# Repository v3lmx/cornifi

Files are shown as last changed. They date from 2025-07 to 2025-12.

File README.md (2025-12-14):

# cornifi keyboard

The cornifi keyboard is a split keyboard based on the [corne](https://github.com/foostan/crkbd) with the physical layout of the [fifi](https://github.com/raychengy/fifi_split_keeb).

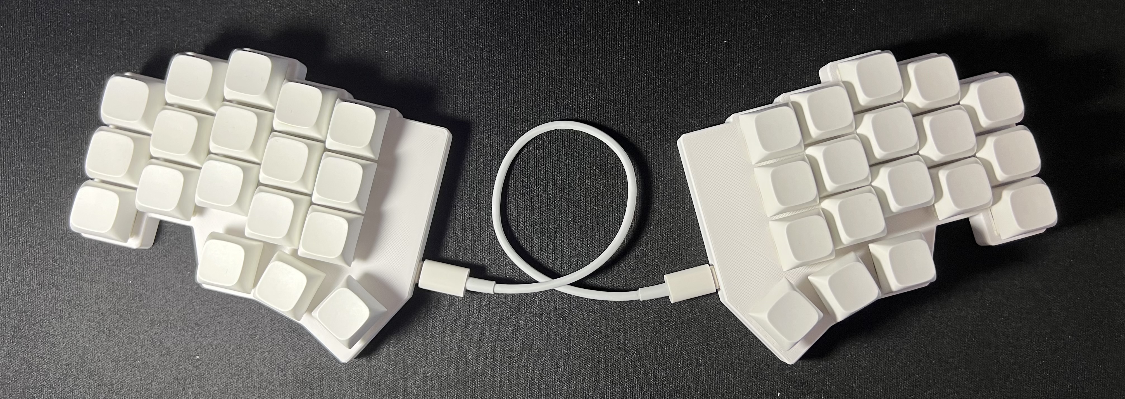
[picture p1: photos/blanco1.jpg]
cornifi keybord photo


## Features 

- 36/40 keys 
- Encoder support 
- Embedded RP2040 controller
- USB-C to connect the halves
- PCB assembly: no soldering required (unless you use encoders)

**Does not have:**
- OLED displays
- RGB
- wireless

## How to get one 

You can order a cornifi keyboard PCB from a PCB manufacturer. See the [pcb ordering guide](docs/pcb_ordering_guide.md).
Cases can be 3d printed, see the [cases](cases/) directory.
You will also need a usb-c cable, cherry MX switches, and keycaps.

I am not currently selling them myself, but if you would be interested, you can vote on [this issue](https://github.com/v3lmx/cornifi/issues/1).

## Firmware

Only [qmk](https://github.com/qmk/qmk_firmware) is supported.

The keyboard is available in the QKM master branch with documentation on installation [here](https://github.com/qmk/qmk_firmware/tree/master/keyboards/cornifi)

### Keymap

There is a default keymap available, but to make your own, I recommend using the [userspace](https://docs.qmk.fm/newbs_external_userspace) feature. You can see an example with my keymap at [v3lmx/qmk_userspace](https://github.com/v3lmx/qmk_userspace).

## Contributing

I'm open to contributions, feel free to open an issue or a pull request.

I probably won't make any changes myself, the current form has everything I need. (Also I probably don't know how).

However, if you submit a pull request, I will gladly take a look at it. Don't hesitate to discuss your ideas in an issue first. 

## Acknowledgements

- foostan for the original [corne keyboard](https://github.com/foostan/crkbd)
- raychengy for the [fifi keyboard](https://github.com/raychengy/fifi_split_keeb)
- [Supul](https://www.fiverr.com/circuitwork32) for the PCB design

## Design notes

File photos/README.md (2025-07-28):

# photos 

## 36 keys



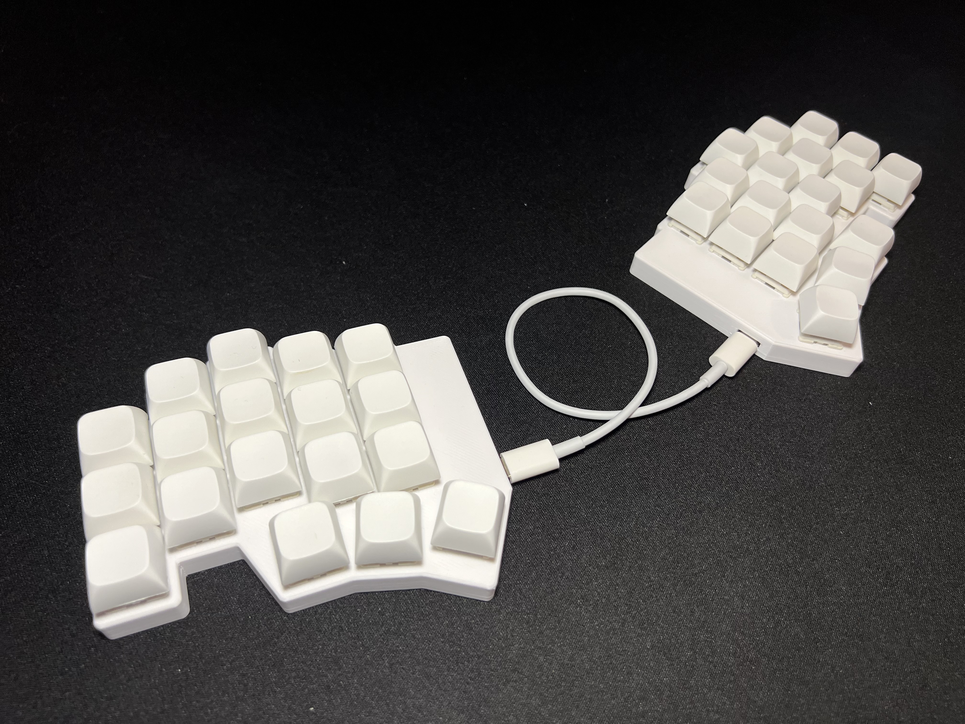
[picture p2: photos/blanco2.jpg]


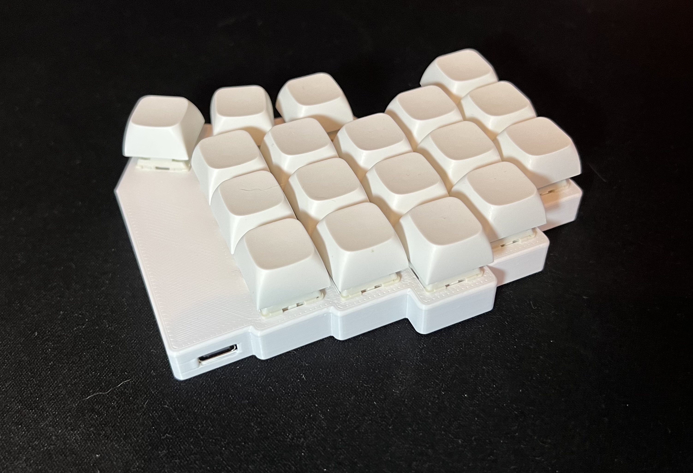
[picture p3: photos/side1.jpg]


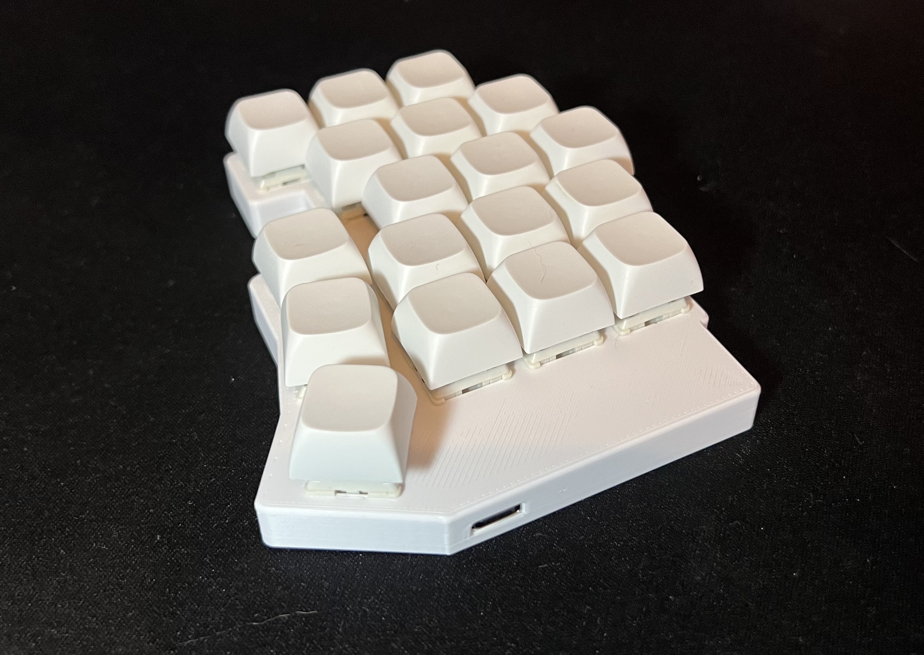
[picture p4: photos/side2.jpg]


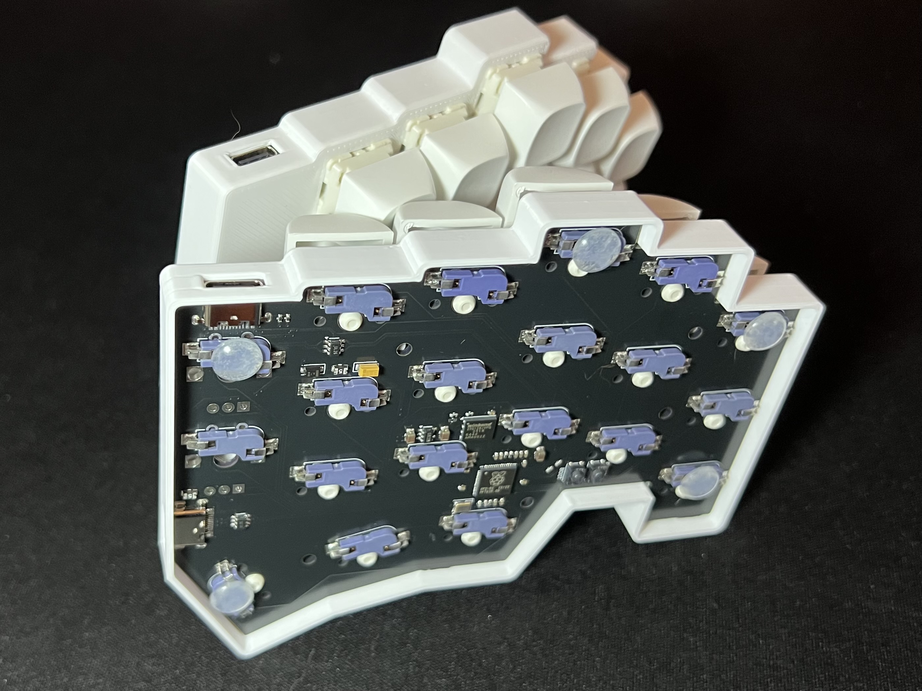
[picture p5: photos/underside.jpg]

>note: this is a preproduction pcb, the through holes are slightly smaller than the final version

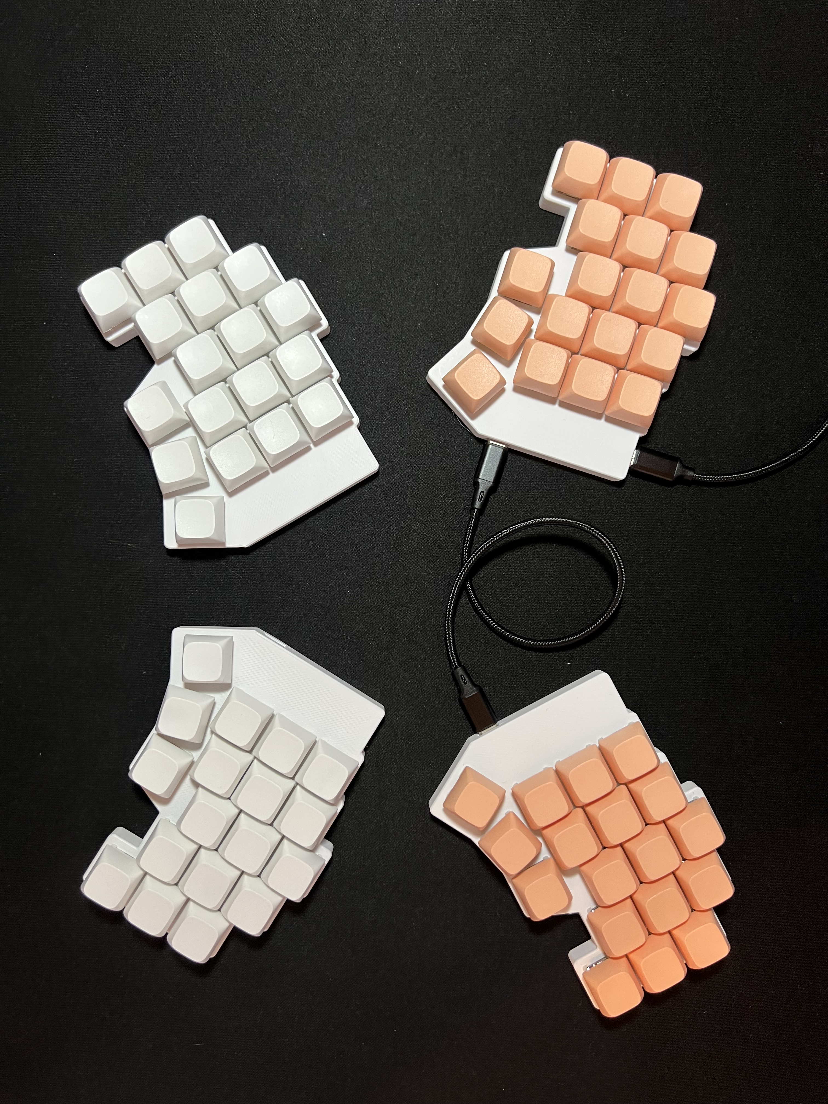
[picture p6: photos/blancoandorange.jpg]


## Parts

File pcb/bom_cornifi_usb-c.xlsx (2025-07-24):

Designator | Qnty | Comment | Footprint | LCSC Part # | MPN
C80,C81,C98,C99 | 4 | 33pF | 402 | C1562
C82,C100 | 2 | 47uF | 3216-10 | C561853
C83,C84,C97,C101,C102,C115 | 6 | 10uF | 805 | C440198
C85,C86,C103,C104 | 4 | 1uF | 402 | C52923
C89,C107,C87,C88,C90,C91,C92,C93,C94,C95,C96,C105,C106,C108,C109,C110,C111,C112,C113,C114 | 20 | 100nF | 402 | C307331
D1,D3 | 2 | PMEG3020EH | SOD-123F | C167645
F3,F4,F5,F6 | 4 | BSMD0805-050-24V | 805 | C910822
J2,J3,J4,J5 | 4 | USB_C | SMD | C2848620
R10,R11,R19,R20 | 4 | 22R | 402 | C25092
R12,R13,R21,R22 | 4 | 1k | 402 | C11702
R14,R23 | 2 | 100k | 402 | C25741
R15,R16,R17,R18,R24,R25,R26,R27 | 8 | 5.1k | 402 | C25905
SW56,SW57,SW58,SW59,SW60,SW61,SW62,SW63,SW64,SW67,SW68,SW69,SW70,SW71,SW72,SW73,SW74,SW75,SW76,SW77,SW78,SW79,SW80,SW81,SW82,SW83,SW84,SW85,SW86,SW87,SW88,SW89,SW90,SW91,SW92,SW93,SW94,SW95,SW96,SW97 | 40 | CPG151101S11 | SMD,14.5x5.9mm | C41430893
SW65,SW66 | 2 | BOOT | SMD | C116501
SW98,SW99 | 2 | RESET | SMD | C116501
U1,U3,U9,U10 | 4 | USBLC6-2SC6 | SOT-23-6 | C7519
U2,U4 | 2 | XC6210B332MR | SOT-23-5 | C424705
U5,U7 | 2 | RP2040 | Package_DFN_QFN:QFN-56-1EP_7x7mm_P0.4mm_EP3.2x3.2mm | C2040
U6,U8 | 2 | W25Q128JVPIQ | WSON-8-EP(5x6) | C190862
Y2,Y3 | 2 | 12MHz | 3225 | C9002

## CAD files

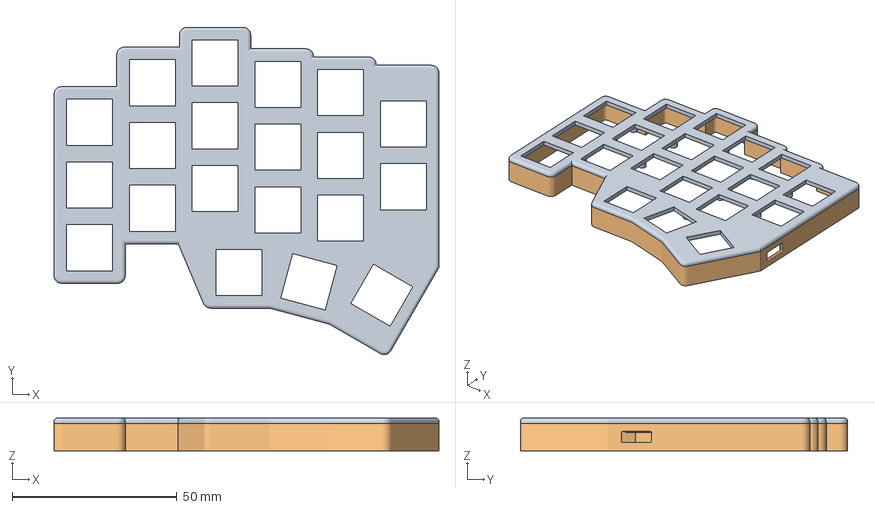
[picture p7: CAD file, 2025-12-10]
cases/cornifi-case-40-v17.3mf
116.9 x 99.4 x 10.0 mm

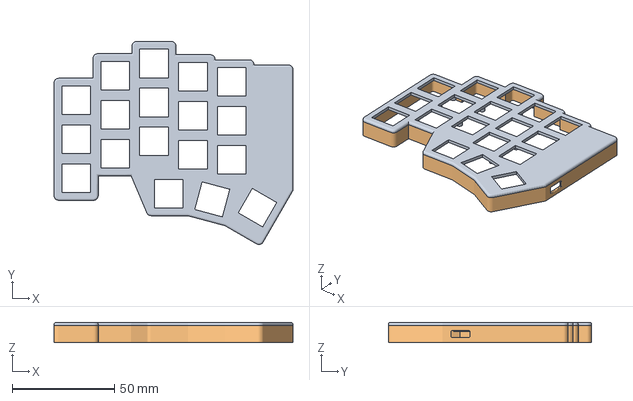
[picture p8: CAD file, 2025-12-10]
cases/cornifi-case-36-v17.3mf
116.9 x 99.4 x 10.0 mm

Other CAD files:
cases/cornifi-case-36-v17.f3d
cases/cornifi-case-40-v17.f3d

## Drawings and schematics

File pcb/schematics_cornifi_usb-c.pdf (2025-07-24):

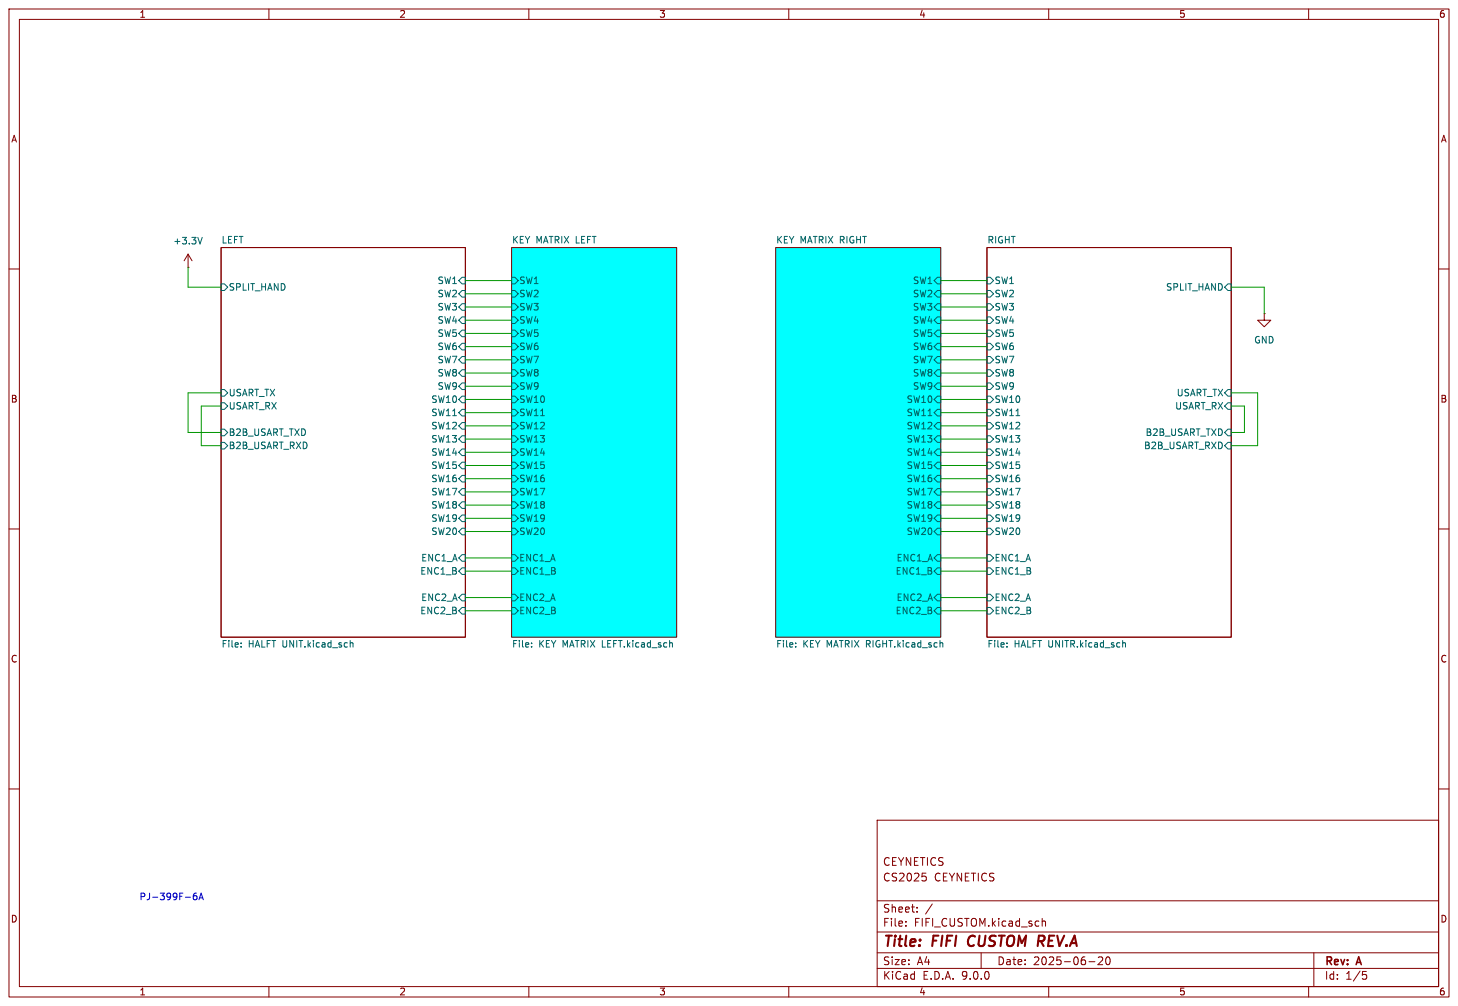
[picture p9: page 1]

File: KEY MATRIX LEFT.kicad_sch SPLIT_HAND

File: KEY MATRIX RIGHT.kicad_sch

File: FIFI_CUSTOM.kicad_sch Sheet: / CS2025 CEYNETICS CEYNETICS

Id: 1/5 Title: FIFI CUSTOM REV.A

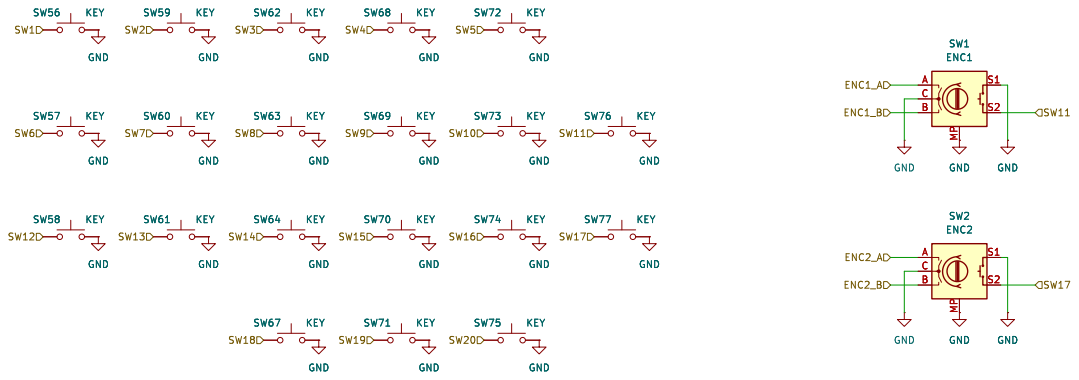
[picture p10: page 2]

Id: 2/5 Title: FIFI CUSTOM REV.A

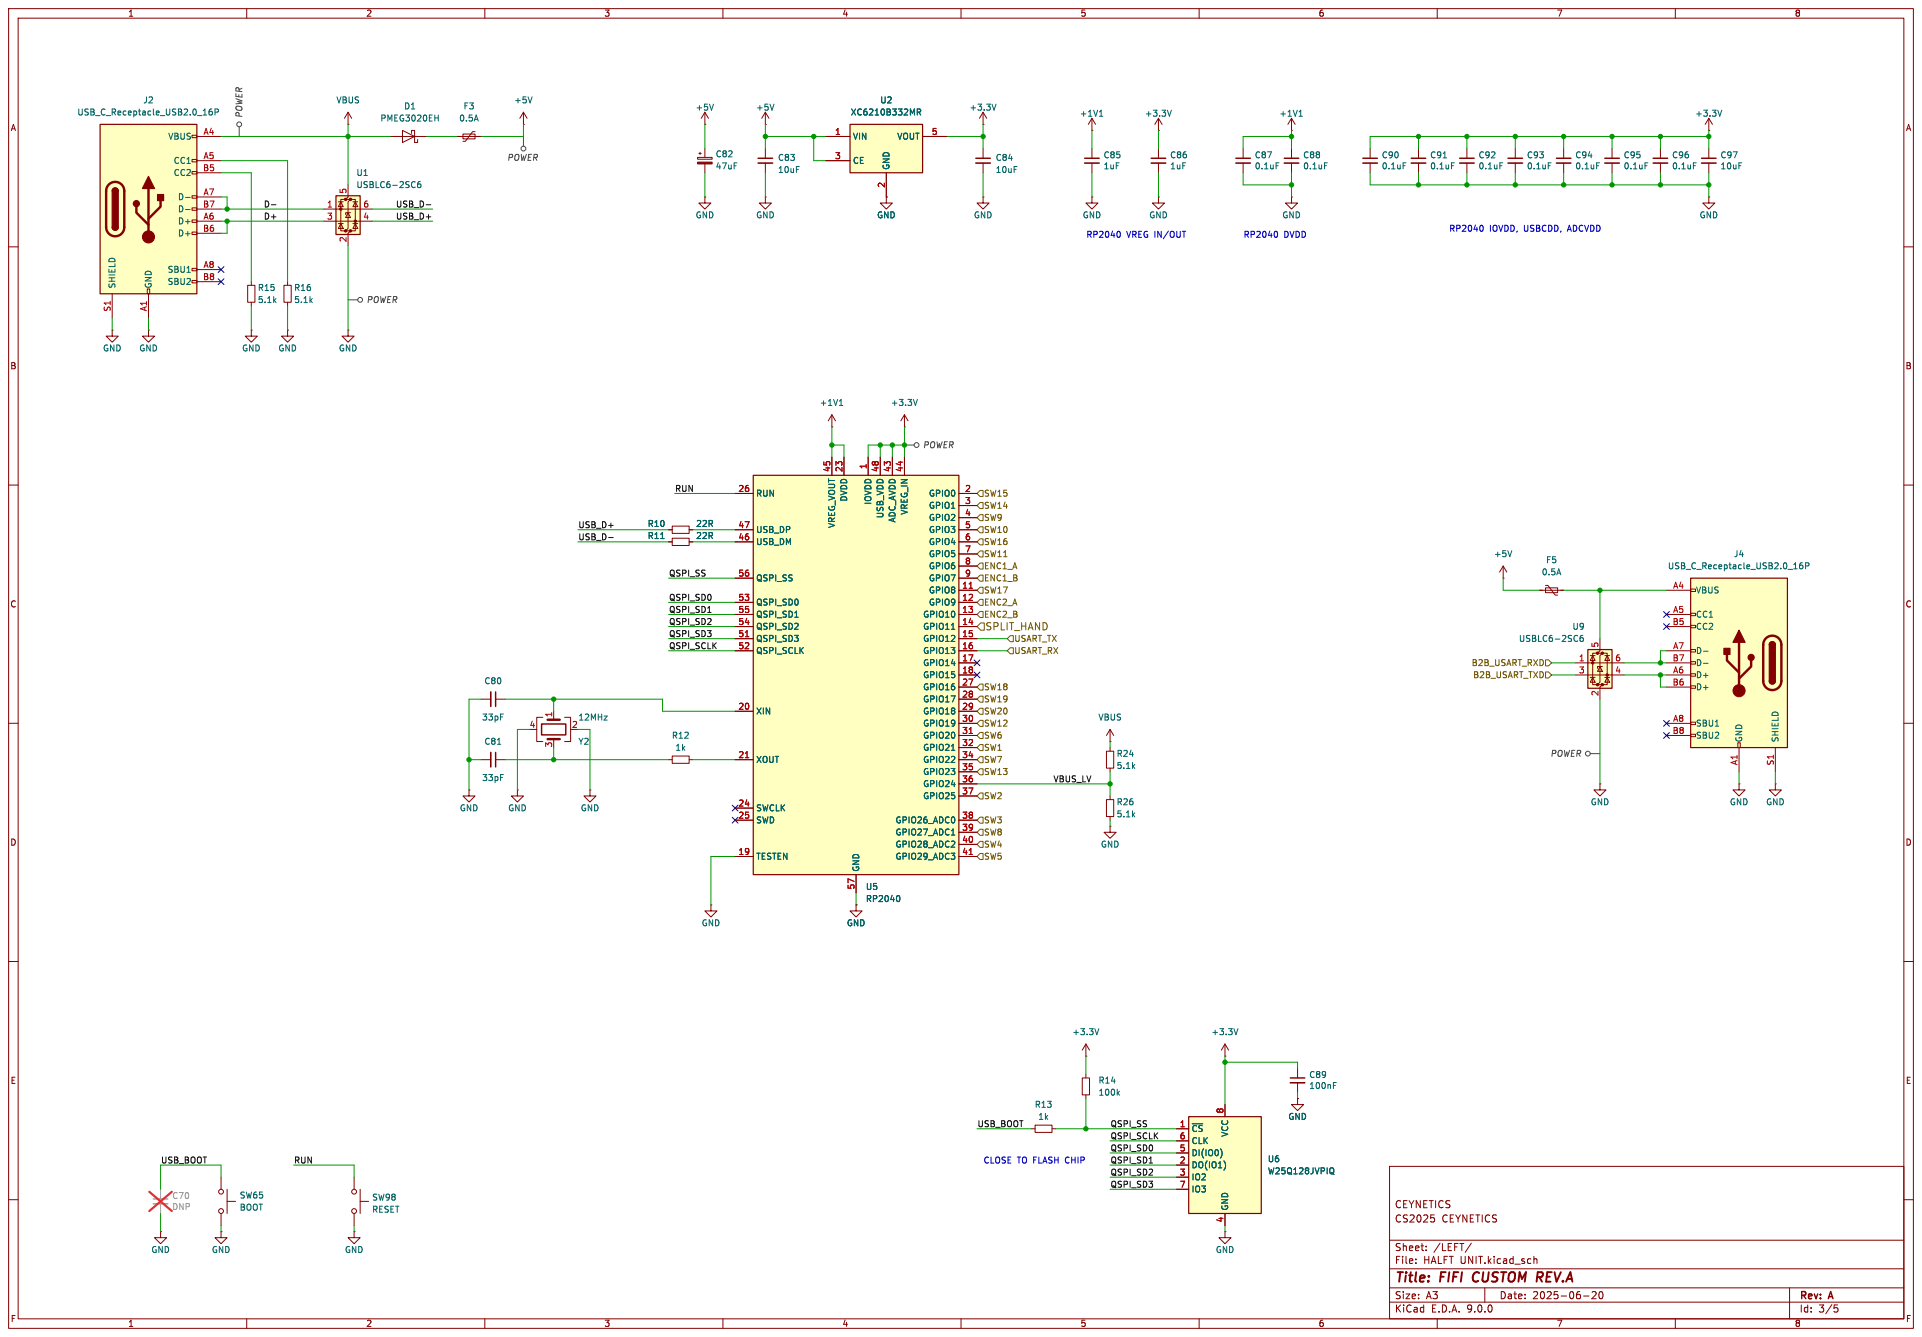
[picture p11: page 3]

~{CS} 1 CLK 6 DI(IO0) 5 DO(IO1) 2

CLOSE TO FLASH CHIP

Id: 3/5 Title: FIFI CUSTOM REV.A

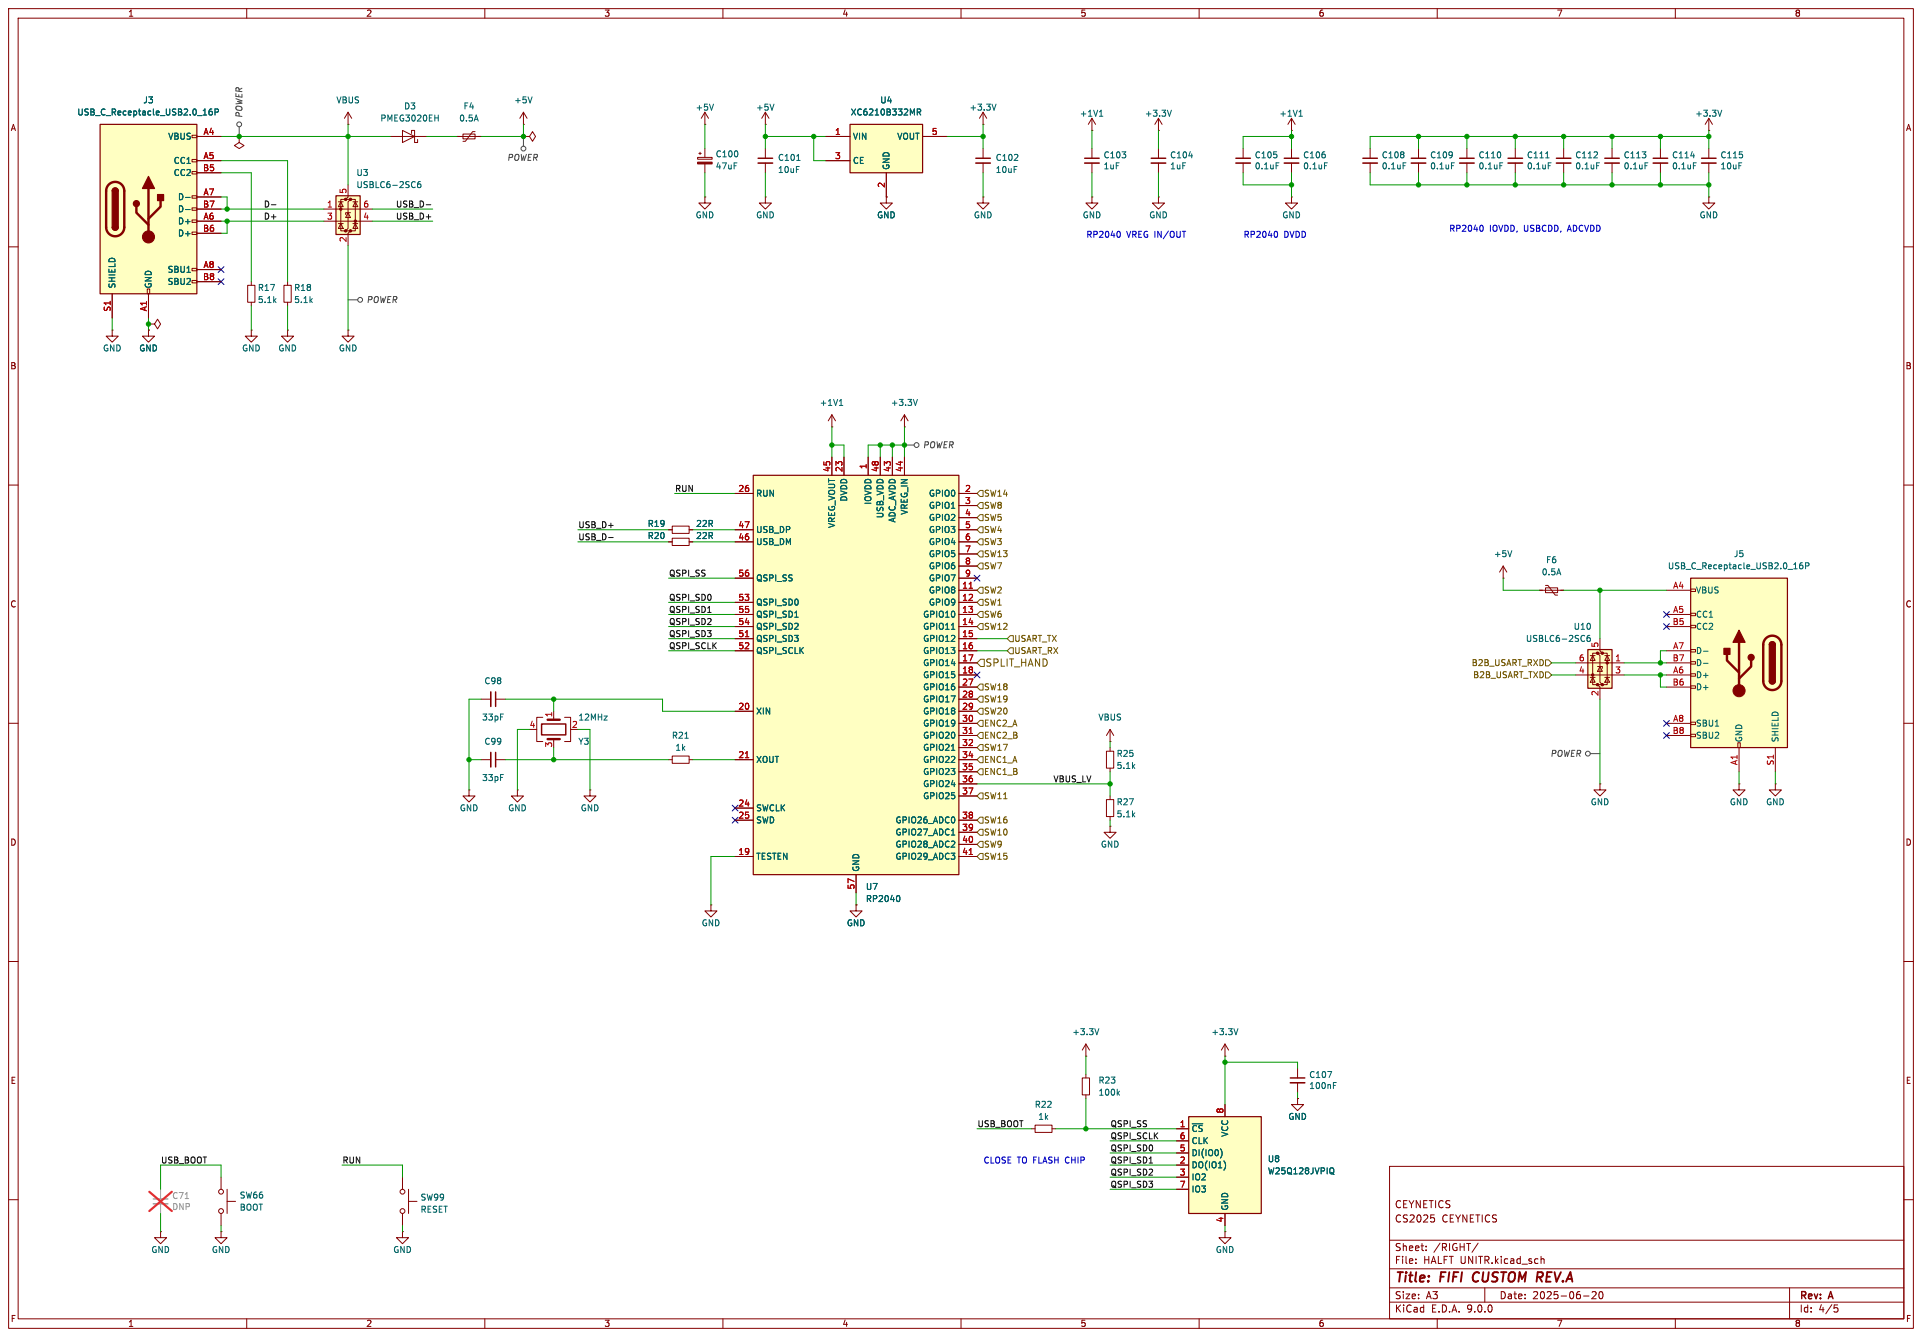
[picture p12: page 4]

CLOSE TO FLASH CHIP GND

~{CS} 1 CLK 6 DI(IO0) 5 DO(IO1) 2

Id: 4/5 Title: FIFI CUSTOM REV.A

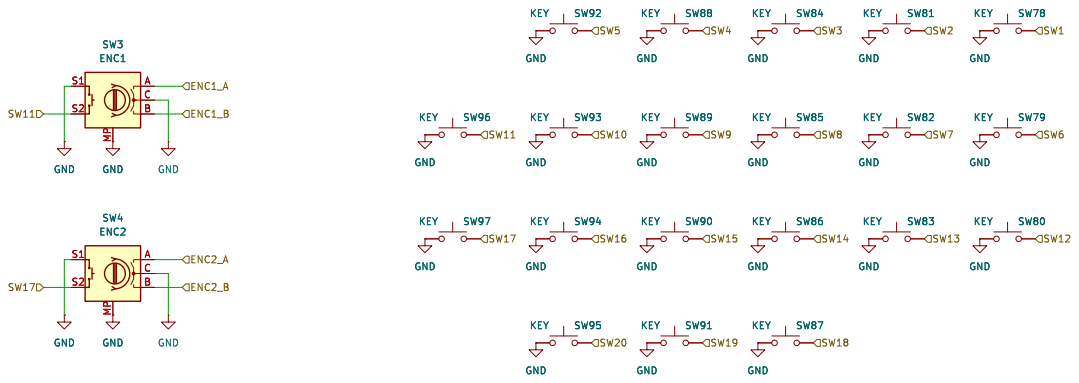
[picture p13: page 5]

Id: 5/5 Title: FIFI CUSTOM REV.A

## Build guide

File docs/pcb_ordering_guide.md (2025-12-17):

# PCB Ordering Guide

This guide will show an example of how to order the cornifi PCB on [JLPCB](https://jlcpcb.com/).

> This does not include other components needed for the keyboard: a case, switches, keycaps, and a usb-c cable.

---

1. Download the files found under `pcb/` (gerber, bom, and cpl).

1. Go to JLCPCB and select "Order Now" on the top right corner.

2. Click on "Add gerber file" and upload the gerber file: `pcb/gerber_cornifi_usb-c.zip` (this may take a while).

3. Most settings default values are good, you need to change this one :
- Different design: 2

And optionnally you can change these as well:
- PCB color: whatever you like
- Surface Finish: LeadFree HASL

> The Dimensions may change when adding PCB assembly, don't worry about it

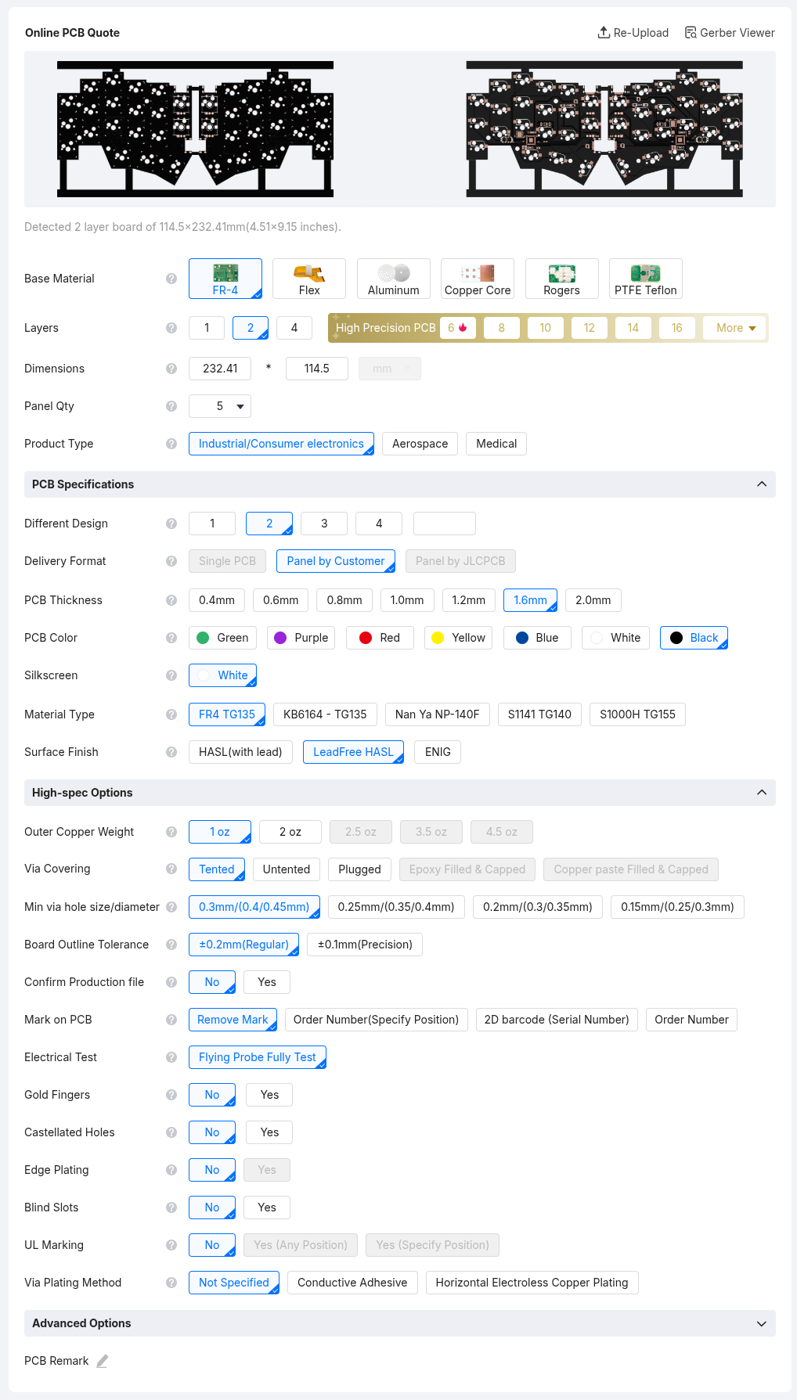
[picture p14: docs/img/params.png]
pcb settings


4. At the bottom, enable "PCB Assembly"
- PCBA Type: Standard
- Assembly Side: Bottom Side
- Confirm Parts Placement: **Yes** (this is important)

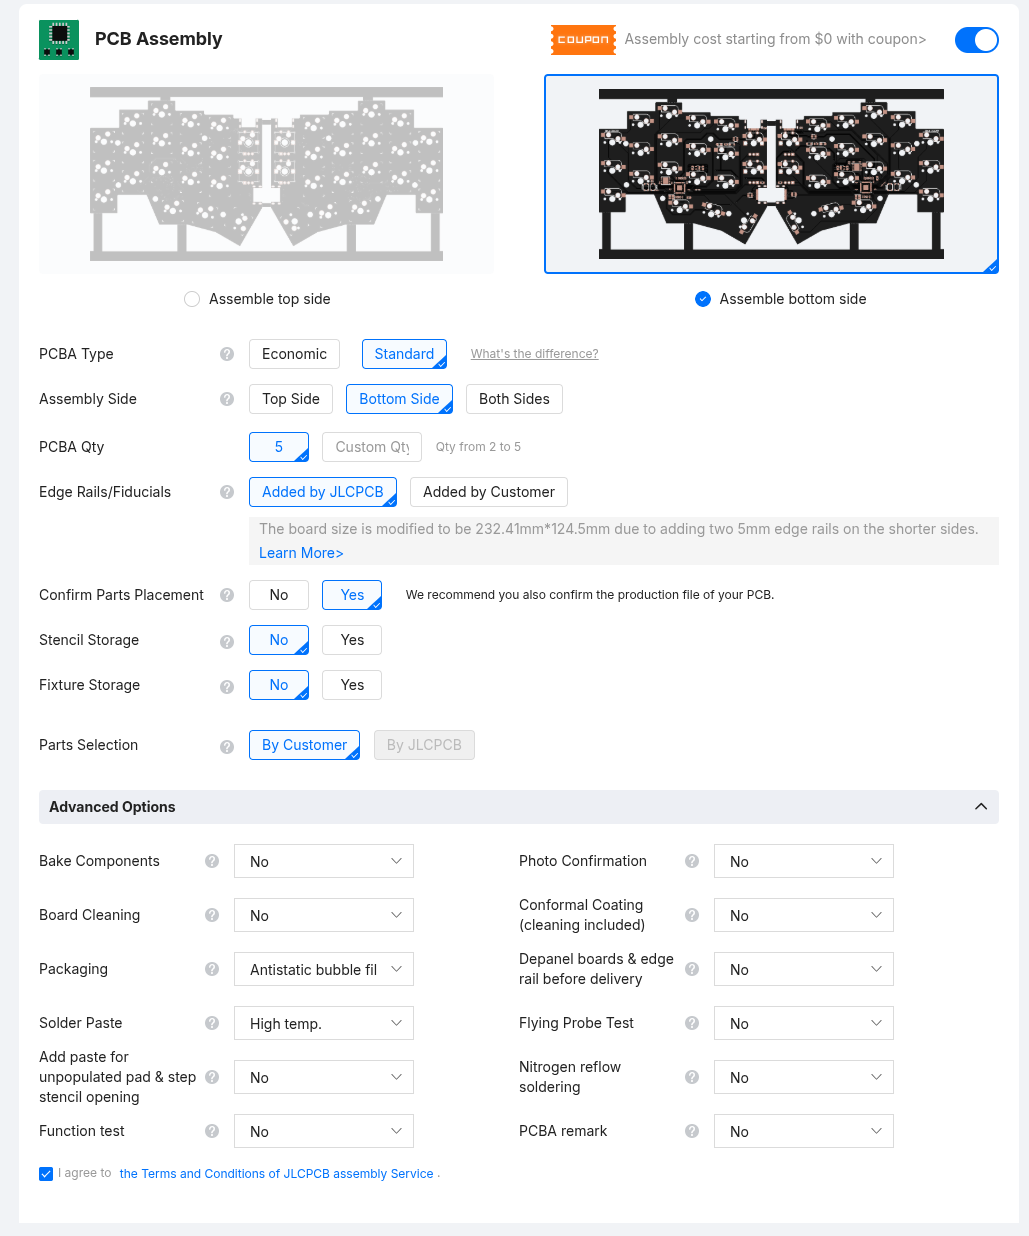
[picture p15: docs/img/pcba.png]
pcba settings


5. Click "Next", you will see you PCB, click "Next" again.

6. You should see two upload boxes, for the CPL and BOM files, and click "Next".
- BOM: `pcb/bom_cornifi_usb-c.xslx`
- CPL: `pcb/cpl_cornifi_usb-c.xslx`

7. You will see a list of components to be assembled. Some manual adjustments may be needed, check if there are any warnings or unselected components:

warning

You need to select all components before going further, so resolve all the warnings or select any missing components, then click "Next".

8. You will then see the PCB with the components placed for assembly. They will most likely be in the wrong spot, but the option "Confirm Parts Placement" will enable a JLCPCB engineer to correct the placement. [0]

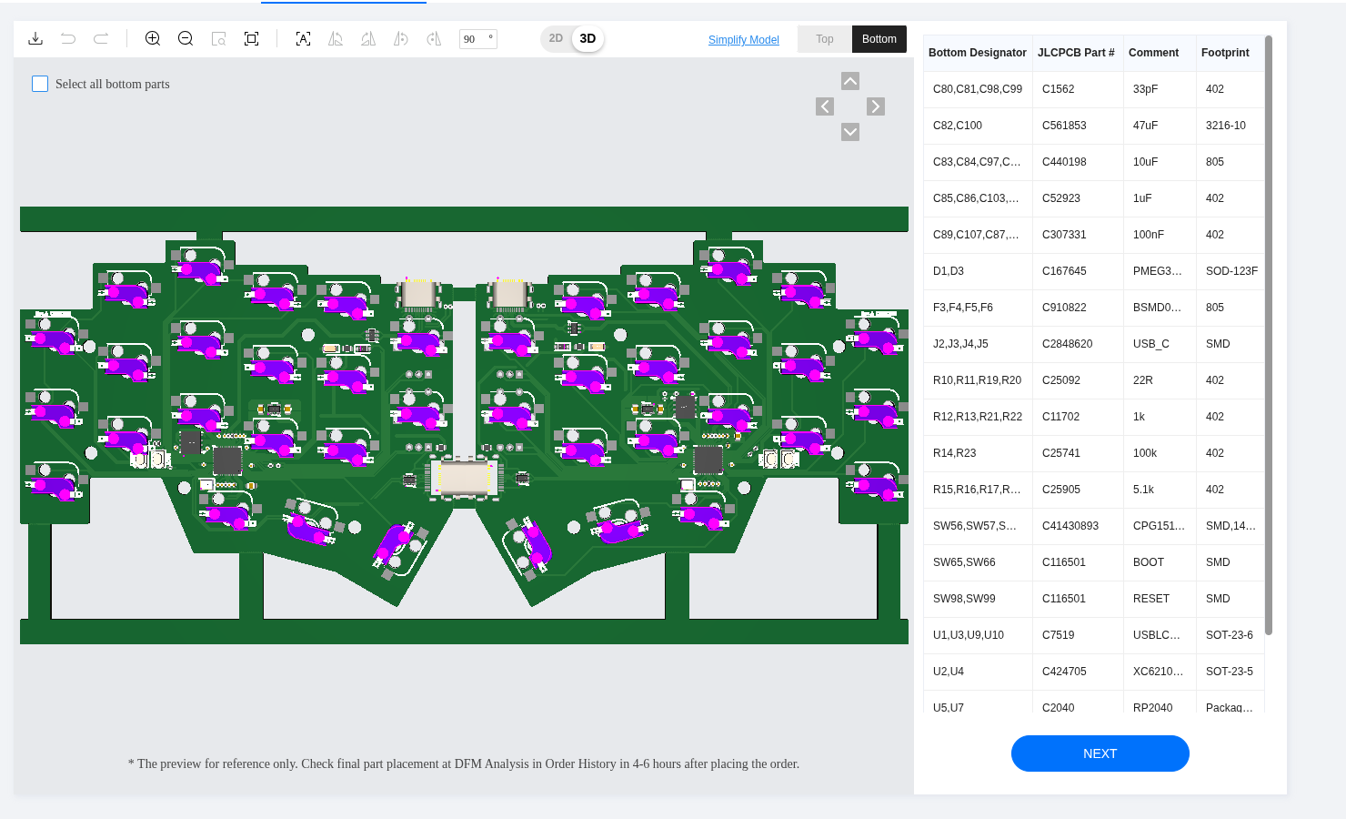
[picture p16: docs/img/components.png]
components


9. Choose the Product Category: "Office Appliance and Accessories", then "Keyboard".

10. Save to cart, and voilà!

> [0] There is a bug when uploading gerber generated with KiCad to JLCPCB that messes up the placement of components, but it will be fixed by them as long as you enable the "Confirm Parts Placement" option.

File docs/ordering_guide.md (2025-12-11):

# Ordering Guide

This guide will show an example of how to order this keyboard on [JLPCB](https://jlcpcb.com/).

---

1. Download the files found under `pcb/` (gerber, bom, and cpl).

1. Go to JLCPCB and select "Order Now" on the top right corner.

2. Click on "Add gerber file" and upload the gerber file: `pcb/gerber_cornifi_usb-c.zip` (this may take a while).

3. Most settings default values are good, here are the ones you may want to change:
    1. PCB color: whatever you like
    1. Surface Finish: LeadFree HASL

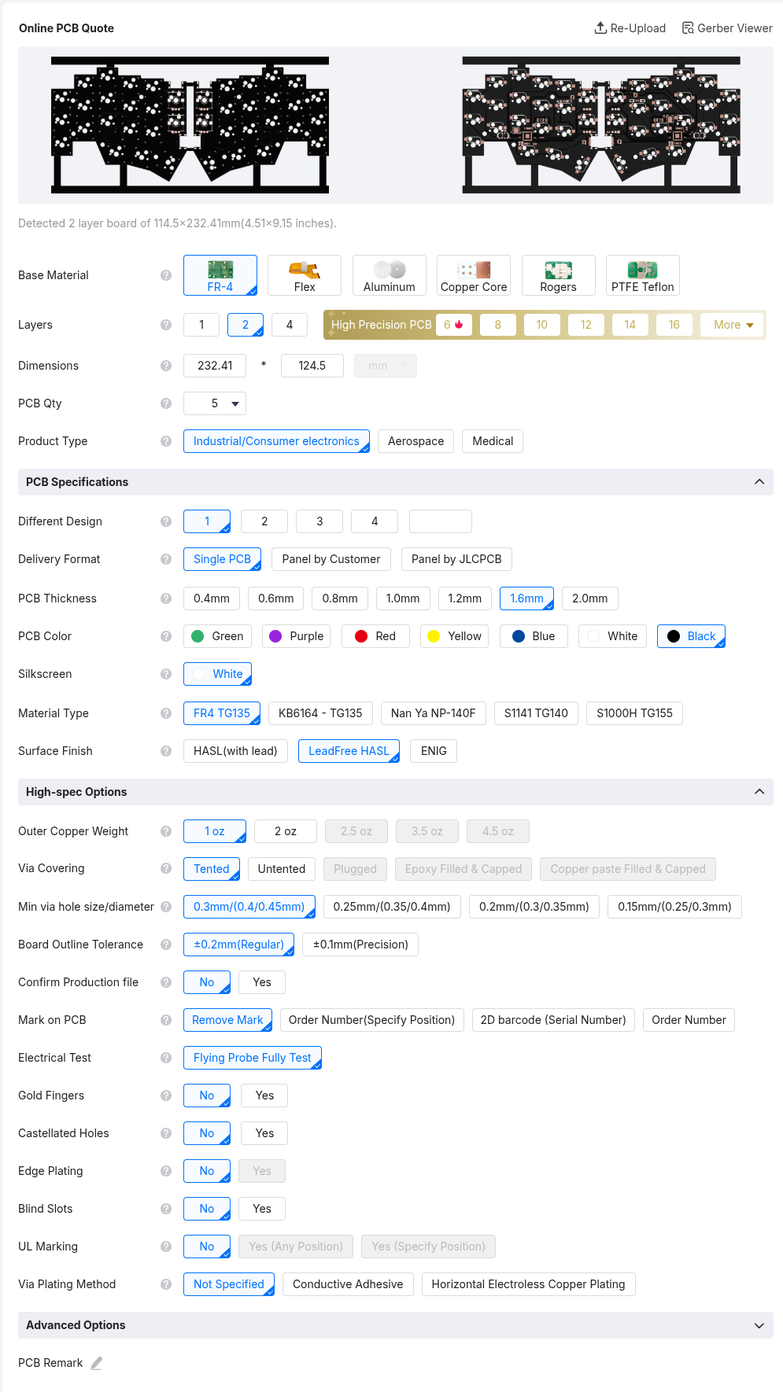
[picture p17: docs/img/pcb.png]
pcb settings


4. At the bottom, enable "PCB Assembly"
    1. PCBA Type: Standard
    1. Assembly Side: Bottom Side
    1. Confirm Parts Placement: **Yes** (this is important)

pcba settings

5. Click "Next", you will see you PCB, click "Next" again.

6. You should see two upload boxes, for the CPL and BOM files, and click "Next".
    1. BOM: `pcb/bom_cornifi_usb-c.xslx`
    1. CPL: `pcb/cpl_cornifi_usb-c.xslx`

7. You will see a list of components to be assembled. Some manual adjustments may be needed, check if there are any warnings or unselected components:

warning

You need to select all components before going further, so resolve all the warnings or select any missing components, then click "Next".

8. You will then see the PCB with the components placed for assembly. They will most likely be in the wrong spot, but the option "Confirm Parts Placement" will enable a JLCPCB engineer to correct the placement. [0]

components

9. Choose the Product Category: "Office Appliance and Accessories", then "Keyboard".

10. Save to cart, and voilà!

> [0] There is a bug when uploading gerber generated with KiCad to JLCPCB that messes up the placement of components, but it will be fixed by them as long as you enable the "Confirm Parts Placement" option.

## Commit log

2025-07-24 feat: add usb-c production files
    [bom_cornifi_usb-c.xlsx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]
2025-07-28 doc: photo pcb disclaimer
2025-12-10 add cases files
    [bom_cornifi_usb-c.xlsx, cornifi-case-36-v17.3mf, cornifi-case-36-v17.f3d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]
